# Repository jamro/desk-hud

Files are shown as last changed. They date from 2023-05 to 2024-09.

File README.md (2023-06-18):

# Desk-HUD

Desk-HUD is a compact side monitor designed to enhance productivity and convenience in your workspace. It features an 11.9-inch touch screen connected to a Raspberry Pi hardware platform, providing quick access to essential features like a todo list, calendar, weather updates, clock, and smart device control for items such as window covers and air conditioning. With Desk-HUD, managing tasks, staying organized, and controlling your environment becomes effortless, all while keeping everything you need within reach on your desk.

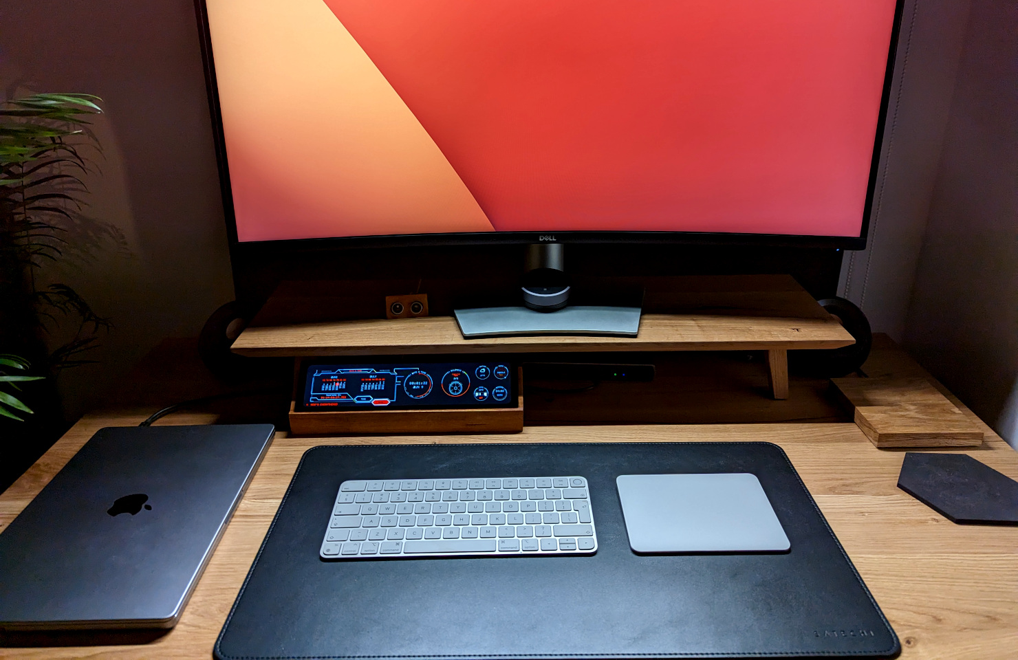
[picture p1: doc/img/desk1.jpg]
Desk view 1


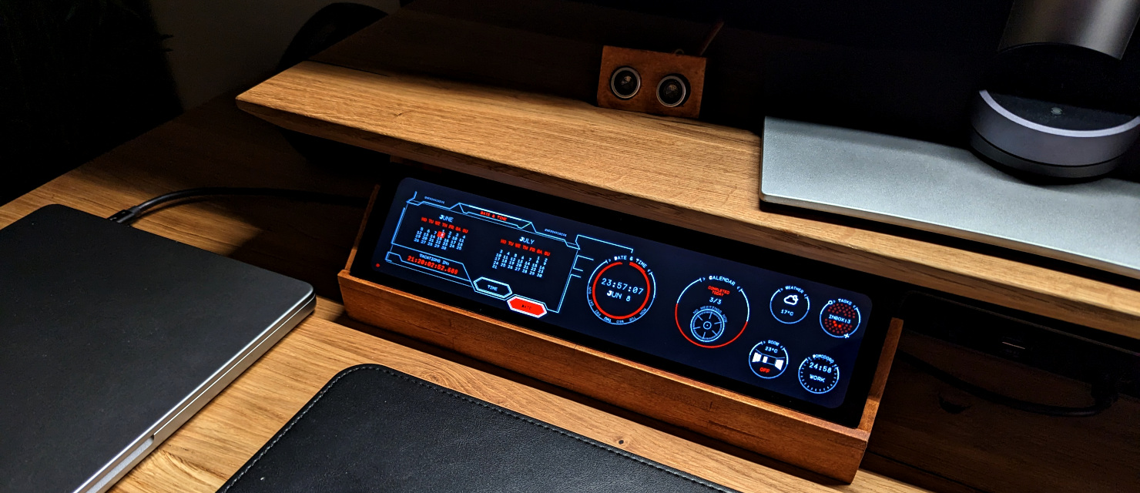
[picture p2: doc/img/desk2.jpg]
Desk view 2


# Key Features

## Date & Time Widget

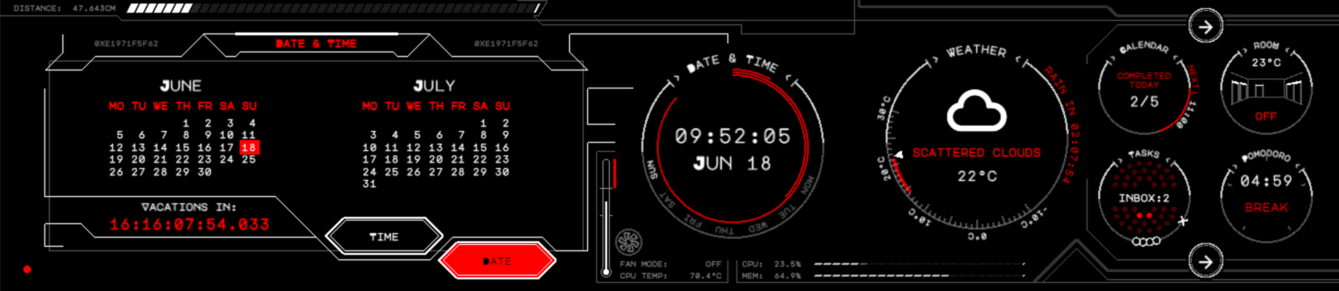
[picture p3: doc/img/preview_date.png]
Date preview


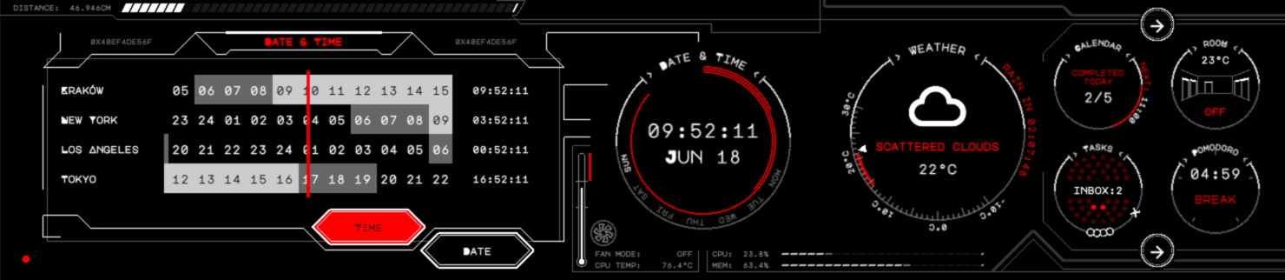
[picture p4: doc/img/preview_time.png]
Time preview


- Clock and calendar
- Special event countdown
- Timezones time conversion

## Weather Widget

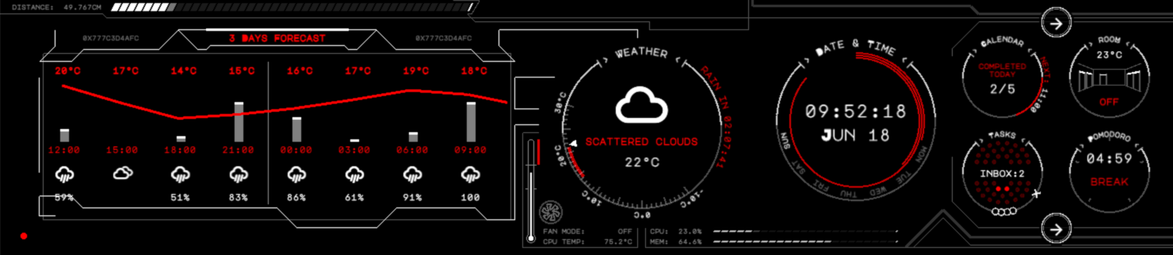
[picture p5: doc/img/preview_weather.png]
Weather preview


- Current weather
- Temperature range for today
- Rain countdown
- Forecast for upcoming days

## Room Widget

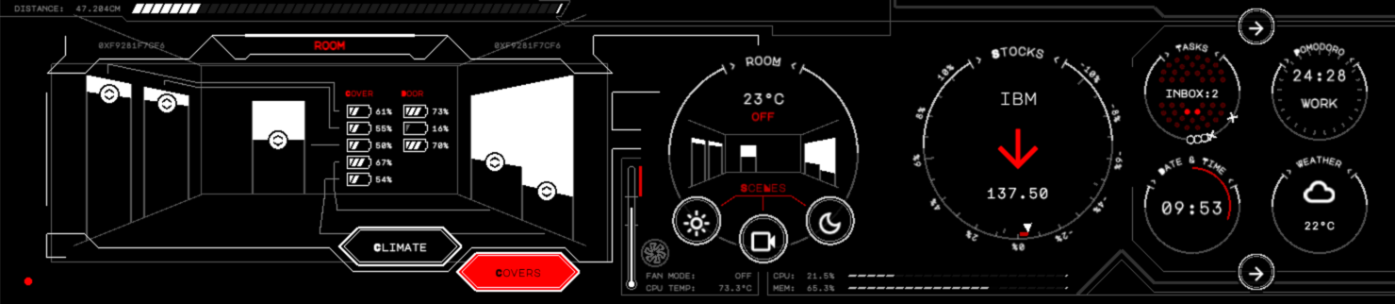
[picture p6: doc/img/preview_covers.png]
Covers preview


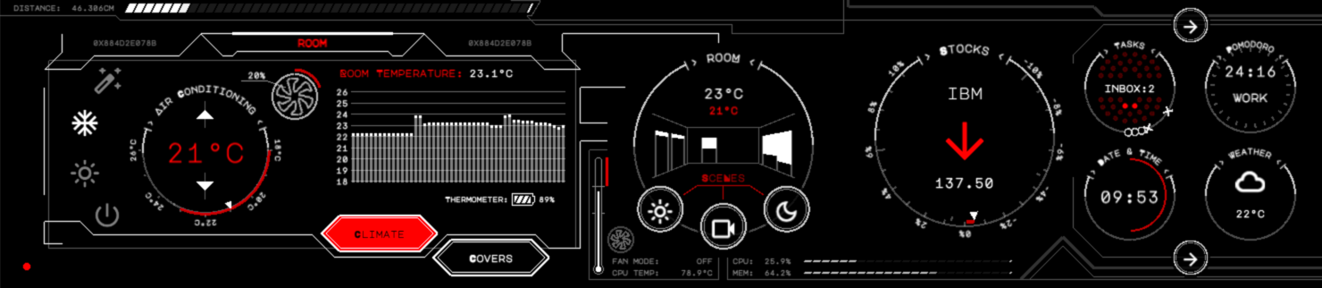
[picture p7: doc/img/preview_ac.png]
Airconditioning preview


- Manual control of window covers
- Window covers scenes: Day, Night, Vide-call (reduced back-light)
- Monitor batteries of smart devices
- Open window alerts
- Air Conditioning control
- Current room temperature
- Room temperature history

## Calendar Widget

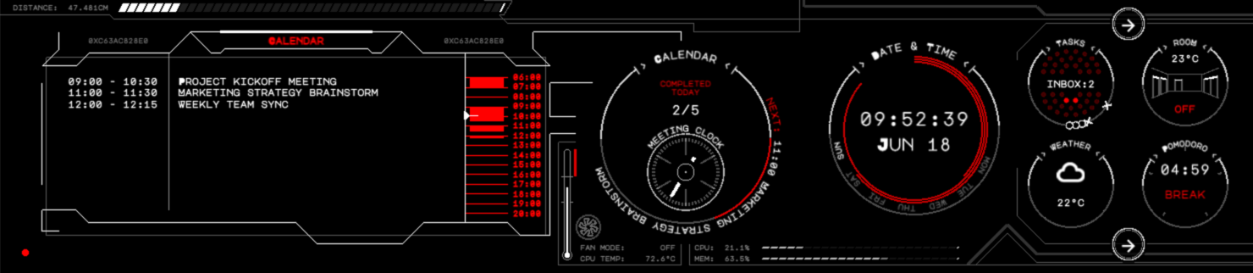
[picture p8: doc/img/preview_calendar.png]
Calendar preview


- Today's meetings
- Busy/available timeline
- Next meeting info
- Ongoing meeting clock

## Todo Widget

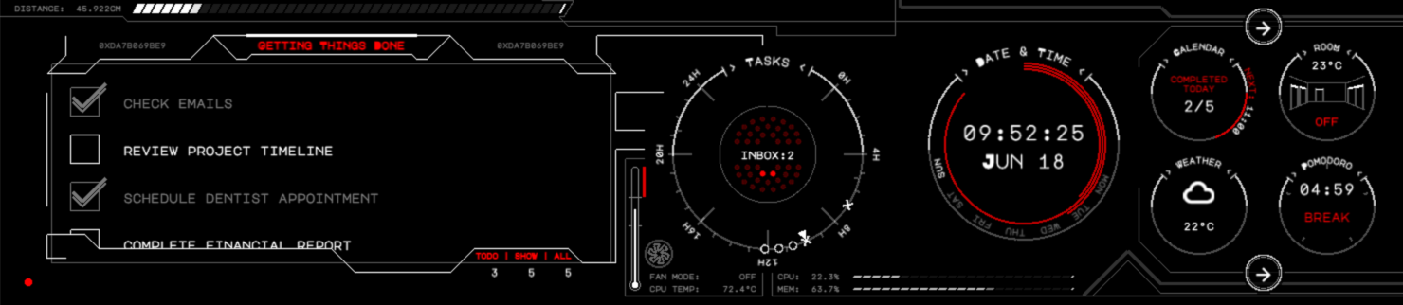
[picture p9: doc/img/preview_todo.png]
Todo preview


- Compatible with [Getting Things Done](https://gettingthingsdone.com/) approach
- List tasks for today
- Complete tasks
- Visualize task completion timeline
- Task inbox status

## Pomodoro Widget

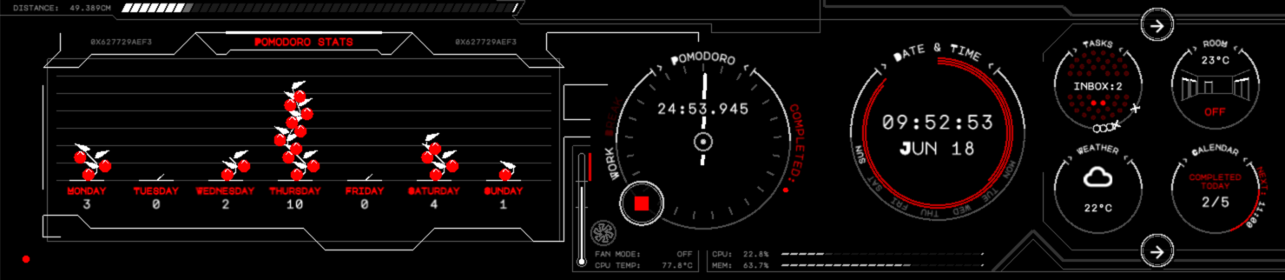
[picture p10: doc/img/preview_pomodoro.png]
Pomodoro preview


- Timer supporting [Pomodoro technique](https://en.wikipedia.org/wiki/Pomodoro_Technique)
- Last week history 

## Stocks Widget

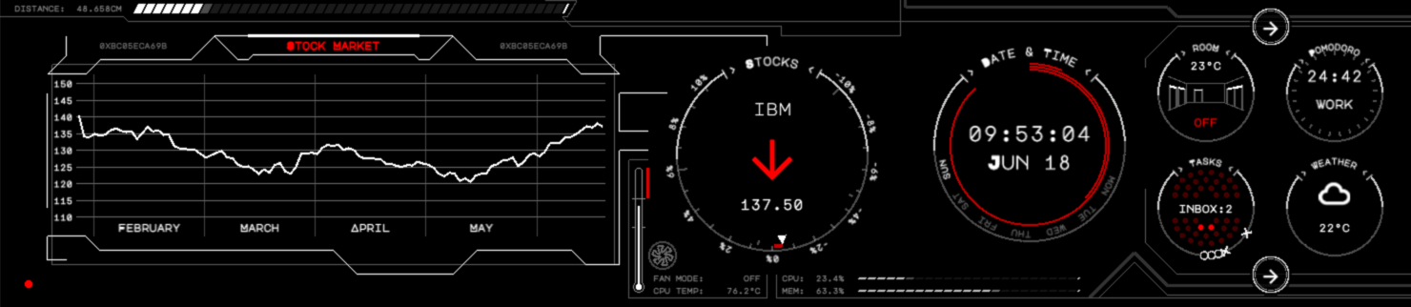
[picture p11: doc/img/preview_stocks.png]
Stocks preview


- Current stock price
- Daily change of the price
- Last months stock history

## Distance sensor

Distance preview

- Darken the screen when no one is around
- Activate Desk HUD automatically by approaching the desk
- Power the screen off when inactive

## System Monitoring

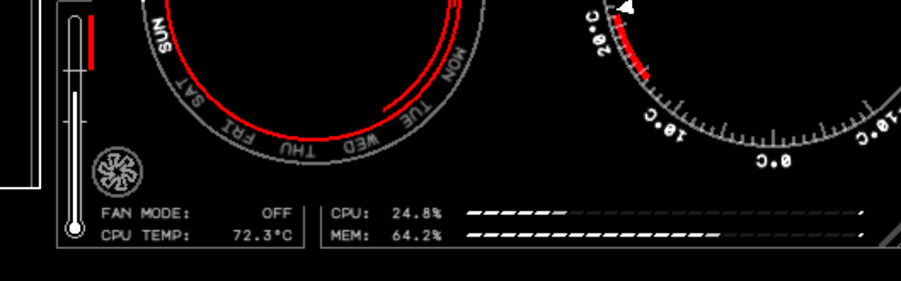
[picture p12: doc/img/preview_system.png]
System preview


- Monitor Desk HUD CPU and memory usage
- Monitor CPU temperature
- Control CPU fan (on/off/auto)

# Demo

You can experience a demo of Desk-HUD by visiting the following URL: [https://desk-hud.jmrlab.com](https://desk-hud.jmrlab.com). Please note that the demo uses simulated data to showcase the features, giving you a feel for Desk-HUD's functionality and is not connected to real systems. 

Additionally, there is a [video](https://www.youtube.com/watch?v=2UuWsG3Lnaw) showcasing the assembled project, complete with the wooden case and touch screen monitor.

# Installation Guide

- [Hardware setup](doc/install_hardware.md)
- [Software installation](doc/install_software.md)
- [Configuration](doc/configuration.md)
- [Wooden case assembly instructions](doc/install_case.md)

# Customization

Desk-HUD is specifically tailored to meet my unique requirements and is not intended as a one-size-fits-all solution. However, the project's source code is open for anyone to fork and customize according to their individual needs and preferences.

Some resources to get started:

- [System Design](doc/system_desgn.md)
- [Setup of Development Environment](doc/dev_setup.md)
- [Development Guide: Create a widget](doc/dev_create_widget.md)

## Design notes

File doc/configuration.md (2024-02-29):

# Configuration

## Location

By default, the configuration file, `desk-hud-config.json` is read from the root directory of the project. However, if you wish to use an alternative location for the config file, you can set the environment variable `DHUD_CONFIG` to the desired file path. This allows for flexibility in specifying the location of the config file to suit your needs. 

To assist you in creating the config file, a template named `desk-hud-config.default.json` is provided within the project. You can refer to this template as a starting point to define your own configurations and customize Desk-HUD according to your preferences.

## Config parameters

The configuration for Desk-HUD is stored in a JSON file.

- **core**: This section contains core settings for Desk-HUD.
  - `port` (number): The port number on which Desk-HUD's server runs.
  - `distance` (object): The distance settings for the distance sensor, specifying the threshold values for waking up and going to sleep modes.
    - `wakeUp` (number): The distance threshold (in centimeters) at which Desk-HUD wakes up from sleep mode.
    - `goSleep` (number): The distance threshold (in centimeters) at which Desk-HUD goes into sleep mode.
  - `powerOffTime` (number): The duration in milliseconds after which Desk-HUD's monitor powers off.

- **dateTime**: This section handles date and time widget configuration
  - `countdown` (object): Specifies a countdown timer with a name and a target date.
    - `name` (string): The name of the countdown timer.
    - `date` (string): The target date for the countdown timer in ISO 8601 format.
  - `timezones` (array): Defines an array of time zones with their IDs and corresponding names.
    - Each timezone object has the following properties:
      - `id` (string): The ID of the time zone.
      - `name` (string): The corresponding name of the time zone.

- **weather**: This section includes settings for weather information.
  - `apiKey` (string): The API key required to access weather data.
  - `lat` (number): The latitude coordinate of the location for weather information.
  - `lon` (number): The longitude coordinate of the location for weather information.

- **hass**: This section pertains to Home Assistant integration.
  - `url` (string): The URL of the Home Assistant instance.
  - `token` (string): The authentication token for Home Assistant.
  - `entities` (object): Defines a mapping of entity names used in Desk-HUD
    - `temp` (string): The entity ID for the temperature sensor.
    - `tempBattery` (string): The entity ID for the temperature sensor battery status.
    - `ac` (string): The entity ID for the air conditioning system.
    - `door1`, `door2`, `door3` (string): The entity IDs for binary door sensors.
    - `cover1`, `cover2`, `cover3`, `cover4`, `cover5` (string): The entity IDs for window cover devices.
    - `door1Battery`, `door2Battery`, `door3Battery` (string): The entity IDs for the battery status of the door sensors.
    - `cover1Battery`, `cover2Battery`, `cover3Battery`, `cover4Battery`, `cover5Battery` (string): The entity IDs for the battery status of the window cover devices.

- **google**: This section pertains to Google integration.
  - `clientId` (string): The client ID for Google integration.
  - `clientSecret` (string): The client secret for Google integration.
  - `clientToken` (string): The client token for Google integration.
  - `tasks` (object): Contains settings related to Google Tasks integration.
    - `inboxId` (string): The ID of the Google Tasks inbox (see Getting Things Done technique).
    - `actionsId` (string): The ID of the Google Tasks actions list (see Getting Things Done technique).
  - `calendars` (array): An array of Google Calendars IDs.

- **stockdata** - allows you to configure the [StockData](http://www.stockdata.org) service integration for Desk-HUD. StockData provides financial market data and analytics.
  - `apiKey` (string): The API key for accessing the StockData service.
  - `symbol` (string): The stock symbol or ticker for which you want to fetch data. 

## Integrations

### Open Weather Maps

To obtain the weather.apiKey for Desk-HUD, you will need to sign up on the OpenWeatherMap website and obtain an API key. Here are the steps to get the API key:

1. Visit the [OpenWeatherMap website](https://openweathermap.org/).
2. Sign up for a free account or log in to your existing account.
3. Once logged in, navigate to the `My API Keys` section.
4. Generate a new API key by clicking on the "Generate" button.
5. Once the API key is generated, copy it to your clipboard.
6. Paste the API key into the `weather.apiKey` parameter in the Desk-HUD configuration file.

### Home Assistant

1. Log in to your Home Assistant instance.
2. Navigate to your user profile or user settings.
3. Locate the "Long-Lived Access Tokens" section.
4. Generate a new access token by clicking on the "Create Token" or similar button.
5. Provide a name for the token to identify its purpose (e.g., "Desk-HUD Integration").
6. Once the token is generated, copy it to your clipboard or save it in a secure location.
7. Paste the Home Assistant token into the corresponding `hass.token` parameter in the Desk-HUD configuration file.

### Google

To set up Google access keys for integration with Desk-HUD, follow these steps:

- In the Google Cloud console, go to Menu `APIs & Services` > `Credentials`.
- Click `Create Credentials` > `OAuth client ID`.
- Click `Application type` > `Desktop app`.
- In the `Name` field, type a name for the credential. This name is only shown in the Google Cloud console.
- Click `Create`. The OAuth client created screen appears, showing your new Client ID and Client secret.
- Click `OK`. The newly created credential appears under OAuth 2.0 Client IDs.
- Save the downloaded JSON file as `credentials.json`
- Open `OAuth consent screen` and yourself to `Test users`
- Once you have `credentials.json`, run the `node ./google_auth.js` script. Follow the instructions provided to complete the authentication process.

Detailed process of obtaining `credentials.json` is described here [here](https://developers.google.com/tasks/quickstart/nodejs)

** Refreshing Access Token **
If your access token has expired, you need to remove `clientSecret` and `clientToken` from `deck-hud-config.json` and rerun `node ./google_auth.js` script.

### StockData

- Visit the StockData website: Go to the StockData website at http://www.stockdata.org.
- Click "Sign In"
- Crete an account
- Get API token and copy it to config file

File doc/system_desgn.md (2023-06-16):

# System Design

Desk-HUD utilizes a client-server architecture where both the client and server components run on the same machine, leveraging the Raspberry Pi hardware platform. The server is implemented in JavaScript using Node.js with Express.js and Socket.IO, and it runs locally at localhost:3000. The client is implemented in JavaScript and utilizes Pixi.js for rendering graphics.

On the client side, multiple widgets runs, each corresponding to a specific backend service. These widgets communicate with their respective backend services to retrieve and display relevant data. This modular design allows for flexibility and scalability in adding or modifying widgets based on individual preferences and requirements.

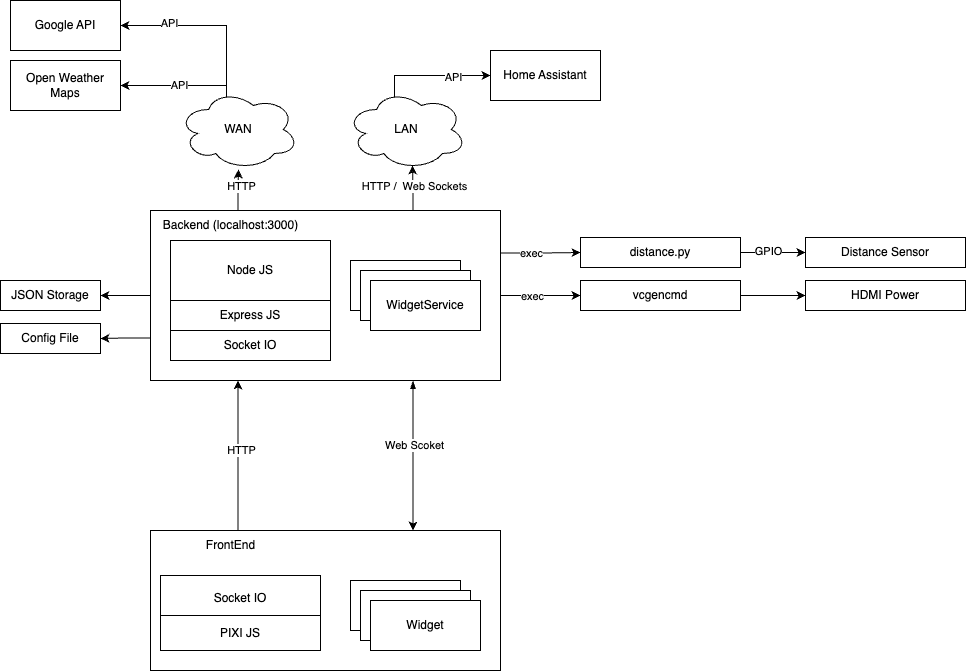
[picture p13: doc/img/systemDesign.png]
System Design Diagram


## Communication

Communication between the client and server is established through web sockets, allowing real-time data exchange. Additionally, an HTTP connection is used to serve static content to the client. This architecture enables seamless and efficient communication between the two components.

The server component of Desk-HUD encompasses multiple services, each responsible for the logic of a specific widget. These services handle data retrieval, processing, and communication with external APIs such as Google API, Open Weather Maps, or Home Assistant. The server also controls peripherals connected to the Raspberry Pi, including a distance sensor and the power of the HDMI monitor.

### Incoming messages

There are several web socket events emitted by the server:

- `config` - configuration details sent after client connected
- `widget` - update of widget data. The message is specific to each eidget
- `distance` - updates from distance sensor
- `system` - updates from system monitor
- `log` - stream of server side logs to show them in browser's dev tool console

### Outgoing messages

There is one web socket event emitted by the client:

- `service` - command for the service (e.g. turn the air conditioning off)

## Persistance

To store essential data, the server employs simple JSON files on the local disk, utilizing the `node-persist` library. This approach ensures persistence and accessibility of necessary information for the widgets and services.

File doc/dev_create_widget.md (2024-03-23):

# Development Guide - Create a widget

This tutorial shows how to create and add a new widget to Desk HUD. During this walkthrough, 
we are going to create "Memory" widget which monitors memory usage on Raspberry PI device

## Initialize an empty widget

- Create new folder for the widget at `src/widgets/memory`
- Create widget class `src/widgets/memory/MemoryWidget.js`:
```js
import Widget from '../../frontend/Widget.js'

export default class MemoryWidget extends Widget {
  constructor() {
    super('memory', "Memory")

    // set header of main widget window
    this.main.title = "memory stats"
  }
}
```
- Add new widget to `src/widgets/widgets.js`:
```js
import MemoryWidget from './memory/MemoryWidget'
...
const widgets = [
  ...,
  MemoryWidget
]
```

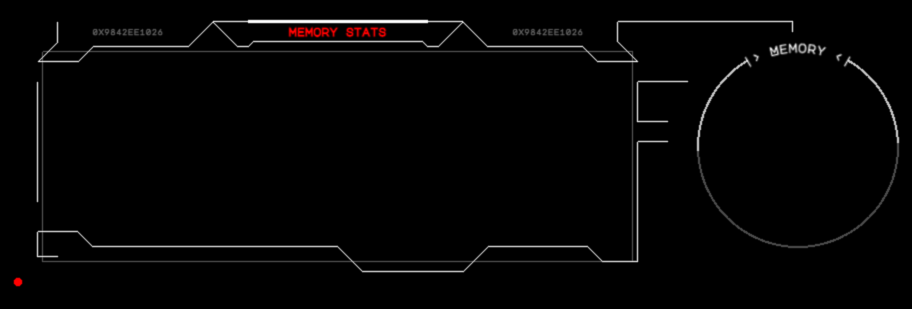
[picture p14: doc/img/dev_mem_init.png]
Empty widget


## Integrate backend service

- Create widget class `src/widgets/memory/MemoryService.js`:
```js
const Service = require("../../backend/services/Service");
const os = require('os');

class MemoryService extends Service {

  constructor(config, io) {
    super(config, io, 'memory')
    this._loop = null
  }

  async start() {
    if(this._loop) {
      clearInterval(this._loop)
    }
    // send update over web socket to the client every 1000ms
    this._loop = setInterval(() => this.update(), 1000)
    this.update()
  }

  async welcomeClient(socket) {
    // send memory usage to the client once it is connected
    this.emit(this.getMemoryUsage(), socket)
  }

  update() {
    // send memory usage updates regularly 
    this.emit(this.getMemoryUsage())
  }

  getMemoryUsage() {
    return {free: os.freemem(), total: os.totalmem()}
  }
}

module.exports = MemoryService
```

- Add new service to `src/widgets/services.js`: 
```js
const MemoryService = require("./memory/MemoryService")
...

const services = [
  ...,
  MemoryService
]
module.exports = services
```

- Extend `MemoryWidget` to display data sent by the service:
```js
import Widget from '../../frontend/Widget.js'
import TextField from '../../frontend/components/TextField.js'

export default class MemoryWidget extends Widget {
  constructor() {
    super('memory', "Memory")

    // set header of main widget window
    this.main.title = "memory stats"

    // store memory usage sent from MemoryService
    this.initState({ usage: 0 })

    // text field to shot memory usage
    this._usageLabel = new TextField('', {
      fontFamily: 'MajorMonoDisplay-Regular',
      fontSize: 15,
      fill: '#ffffff',
      stroke: "#ffffff",
      strokeThickness: 0.5,
      align: 'center',
    })
    this.addChild(this._usageLabel)
  }

  msg2state(msg) {
    // update widget's state and store memory usage there
    return {
      usage: 1 - msg.free / msg.total
    }
  }

  render(renderer) {
    // play nice appear / disappear animations
    this._usageLabel.progress = this.progress

    // display memory usage
    this._usageLabel.text = (100*this.state.usage).toFixed(2) + '%'

    // render the component
    super.render(renderer)
  }
}
```

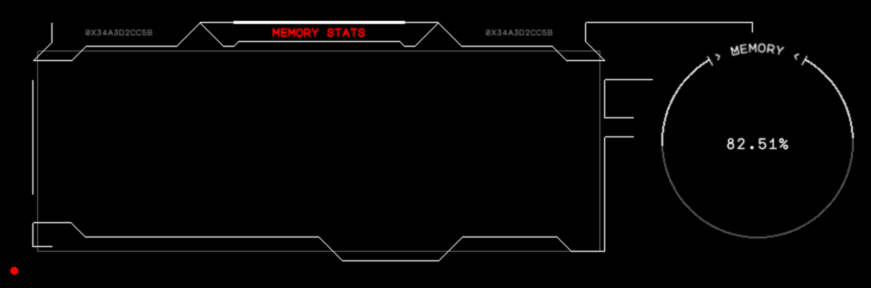
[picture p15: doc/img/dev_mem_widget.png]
Service sending data to the widget


## Store history of memory usage

- Extend `MemoryService` to store the history of memory usage
```js
class MemoryService extends Service {

  constructor(config, io) {
    // ...
    this._history = []
  }

  // ...

  update() {
    this._history.push(os.freemem())
    // limit the history to last minute (60 data points)
    while(this._history.length > 60) {
      this._history.shift()
    }

    // send memory usage updates regularly 
    this.emit(this.getMemoryUsage())
  }

  getMemoryUsage() {
    return {
      free: os.freemem(), 
      total: os.totalmem(),
      history: this._history
    }
  }
}

module.exports = MemoryService
```

- Extend `MemoryWidget` to display memory usage history
```js
import BarChart from '../../frontend/components/BarChart.js'

export default class MemoryWidget extends Widget {
  constructor() {
    // ...

    // create usage chart at main screen
    this._usageChart = new BarChart({
      height: 150,
      width: 530
    })
    this._usageChart.x = -260
    this._usageChart.y = -80
    this.main.getPage(0).addChild(this._usageChart)
  }

  msg2state(msg) {
    // update widget's state and store memory usage there
    return {
      usage: 1 - msg.free / msg.total,
      history: msg.history.map(free => 100 * (1 - free / msg.total))
    }
  }

  render(renderer) {
    // ...
    
    // update usage chart
    this._usageChart.progress = this.progress
    this._usageChart.data = this.state.history

    // render the component
    super.render(renderer)
  }
}
```

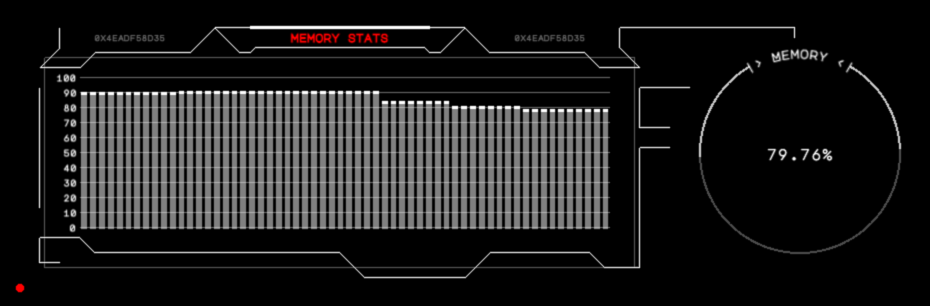
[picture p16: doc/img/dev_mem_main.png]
Usage history integrated


## Error messages

```js
class MemoryService extends Service {

  update() {
    // turn widget into error state and show message
    this.emit({error: "My error message"})
    
    // clear error message
    this.emit({error: null})
  }
}

```

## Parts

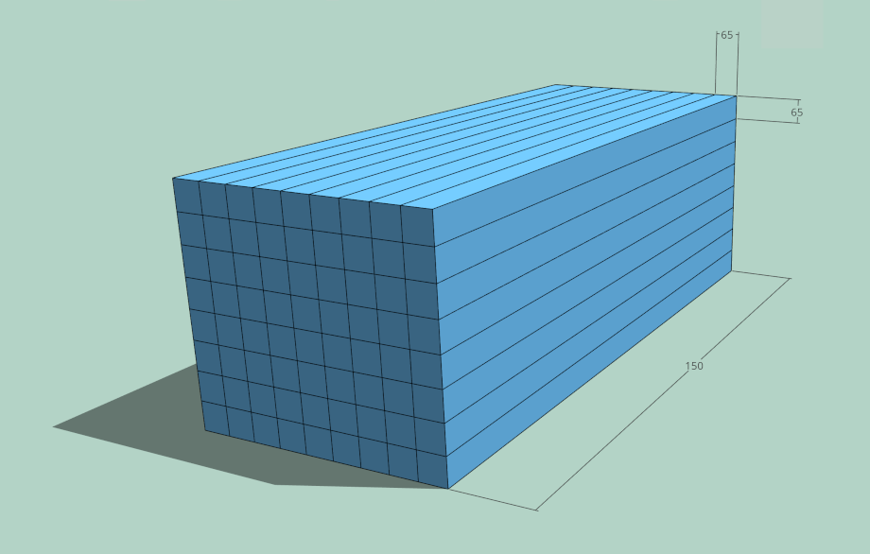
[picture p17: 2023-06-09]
doc/img/components1.png

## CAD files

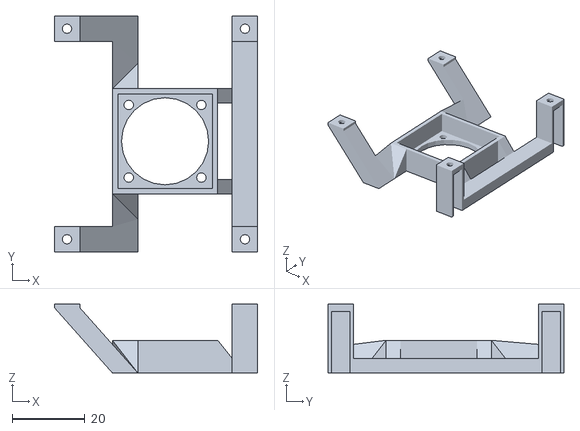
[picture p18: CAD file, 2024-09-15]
doc/stl/desk-hud-fan-mount.stl
56.0 x 65.0 x 19.0

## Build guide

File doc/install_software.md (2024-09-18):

# Install Guide - Software

## Setup project on local machine

- Clone reporistory `git clone https://github.com/jamro/desk-hud.git`
- Enter project folter `cd desk-hud`
- Install dependencies `npm i`
- Rename `desk-hud-config.default.json` to `desk-hud-config.json` and fill missing data. See detailed instructions in [Configuration section](./configuration.md)

## Configuration of Raspberry PI

- Start Raspberry PI and open Terminal 
- change hostname to `deskhud.local`
- Enable ssh `sudo raspi-config`
- Open terminal on your local machine
  - generate public and private keys `ssh-keygen`
  - copy public key to remote host `ssh-copy-id -i ~/.ssh/id_rsa.pub pi@deskhud.local`
  - add key to ssh: `ssh-add`
  - connect to Raspberry PI: `ssh pi@deskhud.local`
- Install Node.js 
```bash
sudo su
curl -fsSL https://deb.nodesource.com/setup_18.x | bash -
sudo apt-get install -y nodejs
```
- Install PM2 `sudo npm install pm2@latest -g`
- Install PM@ log rotate `pm2 install pm2-logrotate`
- Create app folder
```bash
sudo mkdir /var/www
sudo chown pi /var/www
```
- setup env var with path to config file and add it to: `sudo nano /etc/environment`
```
DHUD_CONFIG=/home/pi/desk-hud-config.json 
```
- Expand filesystem `sudo raspi-config` > `Advanced Options` > `Expand Filesystem`
- Disable screen saver `xset s off` (on a Terminal running on Raspberry PI Desktop)
- On your local machine
  - copy config to Raspberry PI: `scp desk-hud-config.json pi@deskhud.local:/home/pi/desk-hud-config.json`
  - provision remote host `npm run provision-remote`
  - deploy `npm run deploy`
- on Raspberry Pi Desktop, open web browser, go to http://localhost:3000 and go full screen

## Enable auto start after boot
- connect to Raspberry PI: `ssh pi@deskhud.local`
- make sure PM2 starts automatically after boot `pm2 startup`
- edit autostart: `nano ~/.config/wayfire.ini` and add following lines
```
[autostart]
command = chromium-browser --kiosk http://localhost:3000/
```
- Reload of the page may be necessary sine Desk-HUD server may not be immediately available 

In order to exit Chromium kiosk mode, press Ctrl+F4

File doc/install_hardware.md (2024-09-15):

# Install Guide - Hardware

## Shopping List

Necessary hardware:
- [Raspberry PI 5](https://www.raspberrypi.com/products/raspberry-pi-5/)
- [Waveshare 11.9inch HDMI touch screen](https://www.waveshare.com/11.9inch-hdmi-lcd.htm)
- [SparkFun Ultrasonic Distance Sensor - HC-SR04](https://www.sparkfun.com/products/17777)
- [Jumper Wires female-female](https://blog.sparkfuneducation.com/what-is-jumper-wire)
- [32GB SD Card with Raspberry Pi OS](https://projects.raspberrypi.org/en/projects/raspberry-pi-setting-up/2)
- [Angle USB-C Cable](https://eu.ugreen.com/collections/cables/products/ugreen-usb-c-to-usb-c-cable-60w-1?variant=40400840556627)
- [20W USB Charger](https://eu.ugreen.com/collections/chargers/products/power-supply-pd-3-0?variant=40296226586707)
- [Raspberry Pi 4 Fan and Heatsink](https://www.adafruit.com/product/4794)
- [3D printed fan mount](stl/desk-hud-fan-mount.stl) (Optional)

## Assembly hardware

Mount Raspberry PI to the [touch screen](https://www.waveshare.com/11.9inch-hdmi-lcd.htm) with included screws and distances. Connect HDMI and touch screen USB with included adapters. Install SD Card with Raspberry PI OS.

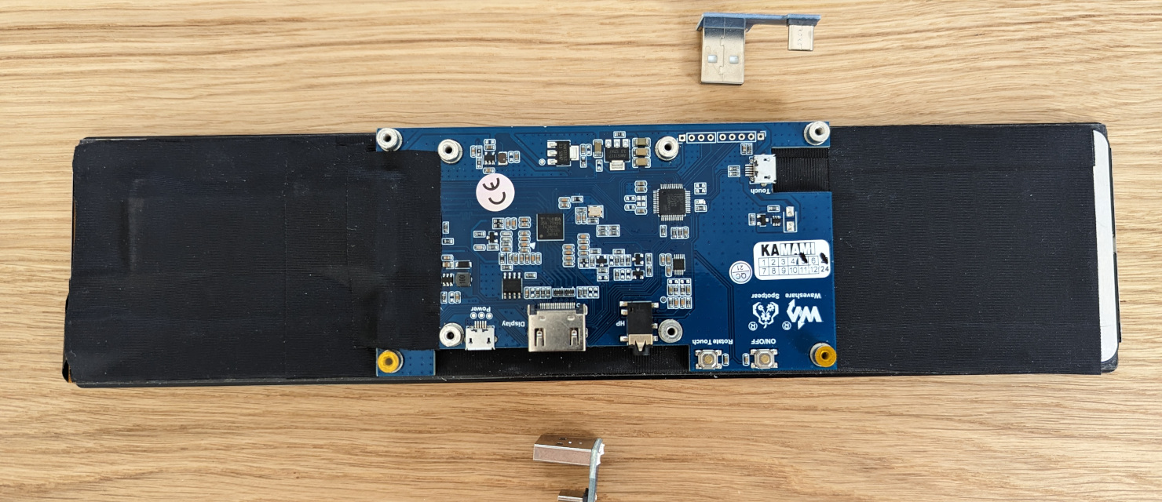
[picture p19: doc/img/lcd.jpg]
Touch screen back


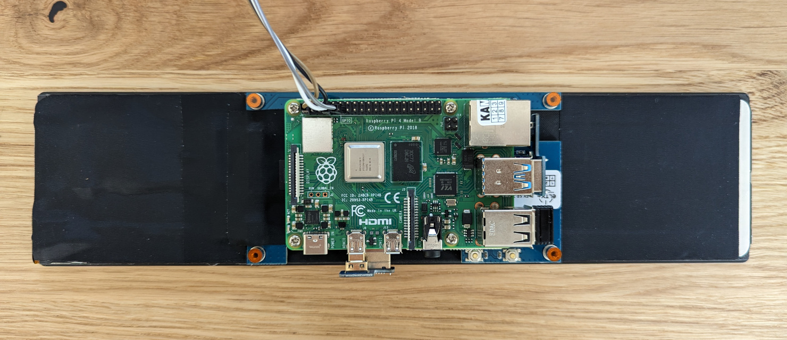
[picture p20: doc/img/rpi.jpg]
Raspberry PI + Touch screen


Wire [distance sensor](https://www.sparkfun.com/products/17777) to GPIO pins of Raspberry PI. Connect the GND at first, otherwise, it will affect the normal work of the module.  

Wire fan to ensure proper cooling of the device. Mount the fan to the case in the place where it can efficiently cool the CPU down. Install the heatsink on Raspberry PI CPU.

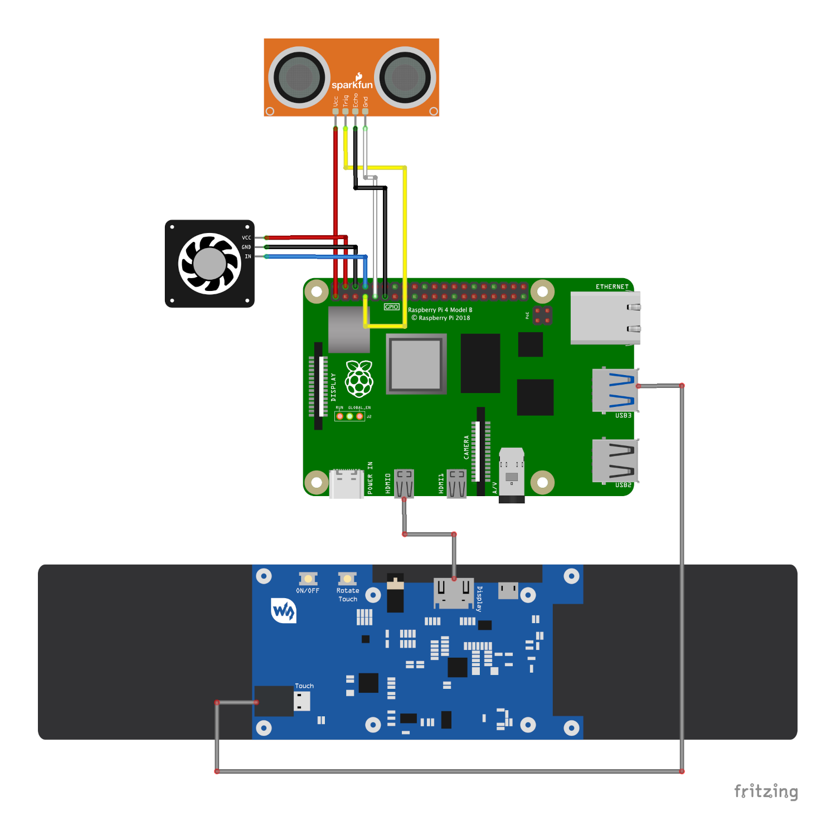
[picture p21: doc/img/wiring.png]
Wireing


3D print the [fan mount](stl/desk-hud-fan-mount.stl) and mount it to the case.

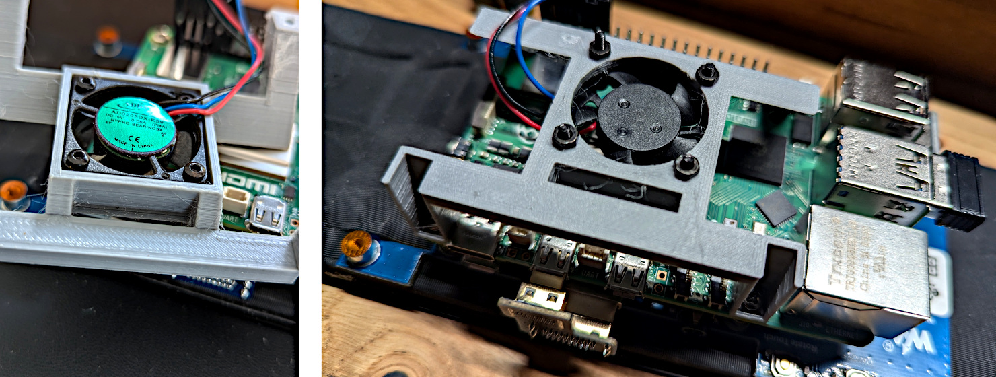
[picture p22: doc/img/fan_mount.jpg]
Fan mount


Power up Raspberry PI by connecting to USB charger. Make sure that touch screen is working correctly. It may have wrong orientation. Fix it using "Rotate Touch" button on the back of the screen 

## Troubleshooting

### Screen is Rotated
1. Open `Menu` > `Preferences` on Raspberry Pi
2. Select `Screen Configuration`.
3. In the new window, right-click the display.
4. Select `Orientation` and choose one of the four options (most probably **Left**).
5. Click the green check to confirm and apply the new orientation.

### Touch Screen is Rotated
- Use the hardware button on the back of the screen to change the orientation of the touchscreen.

### Screen is Black
1. **Ensure Power Supply:** Make sure your Raspberry PI is powered with a 5A power supply (25W or more).
2. **Toggle Power:** Try to turn the screen on/off using the physical button on the screen.
3. **Test with Secondary Screen:** Connect the Raspberry PI to another screen through HDMI output to verify if the Raspberry PI is working correctly.
4. **Direct Power to Screen:** Connect the power supply directly to the screen and HDMI cable from the screen to the Raspberry PI to check if the screen functions.
5. **USB Cable Power:** Replace the power supply by connecting a USB cable directly to the Raspberry PI to see if it provides enough power to the screen.
6. **Check Cables:** Replace the HDMI and USB cables with the connectors included in the screen kit to ensure they are functioning correctly.

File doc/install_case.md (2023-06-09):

# Install Guide - Wooden Case

The wooden case for Desk HUD is built from square sticks glued together. You will need the following materials and follow these step-by-step instructions:

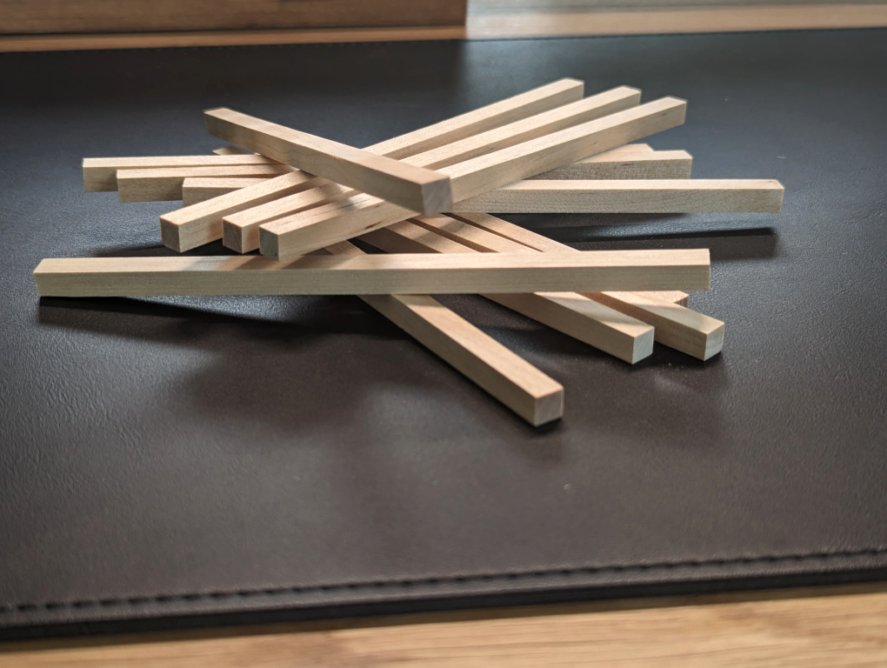
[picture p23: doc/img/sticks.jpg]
Wooden Sticks


## Materials:

- 72 Wooden square sticks: 150mm x 6.5mm x 6.5mm
- Wood glue
- Sandpaper
- Oak-colored paint or wood stain

## Instructions:

Begin by preparing the wooden sticks. Keep 38 sticks at the length of 150mm, cut 24 sticks to 75mm, 2 sticks to 65mm, and 62 sticks to 50mm. Ensure all the cuts are clean and accurate.

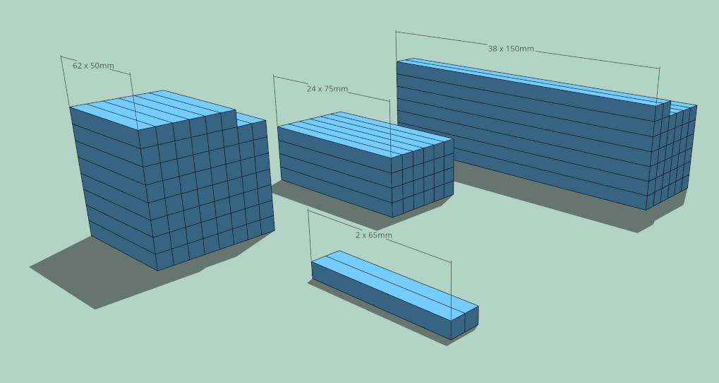
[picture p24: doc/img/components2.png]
Components


Start building the first layer of the case. Apply a thin layer of wood glue on the sides of the sticks and press them together firmly. Ensure the sticks are aligned properly. Allow the glue to dry according to the manufacturer's instructions before proceeding to another layer

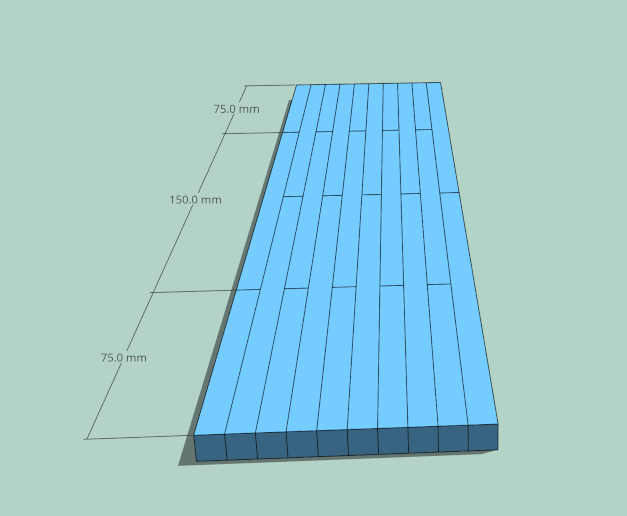
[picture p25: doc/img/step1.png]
Step 1


Repeat the previous step to assemble the subsequent layers of the case, following the provided images as a guide. Take care to align the sticks accurately and maintain the desired shape and dimensions of the case.

Step 2

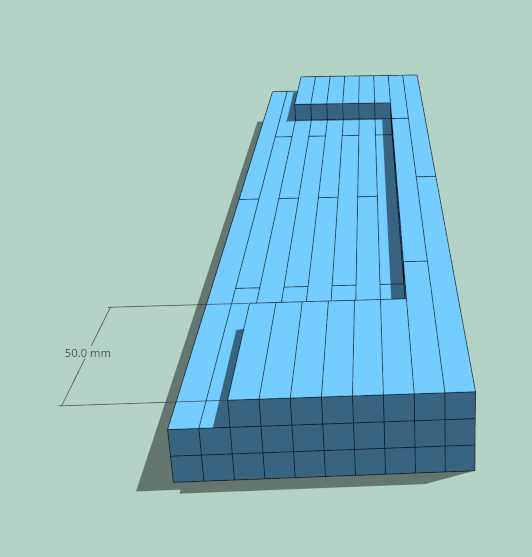
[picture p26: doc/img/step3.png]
Step 3


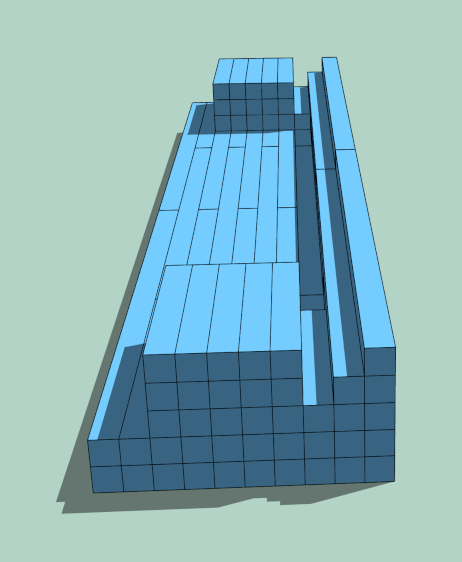
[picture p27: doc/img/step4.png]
Step 4


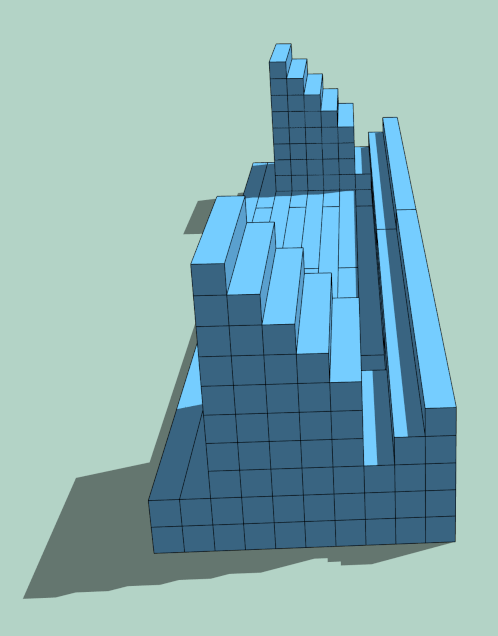
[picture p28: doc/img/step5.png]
Step 5


Use sandpaper to remove corners of the stairs-like surface and turn it into a smooth edge.

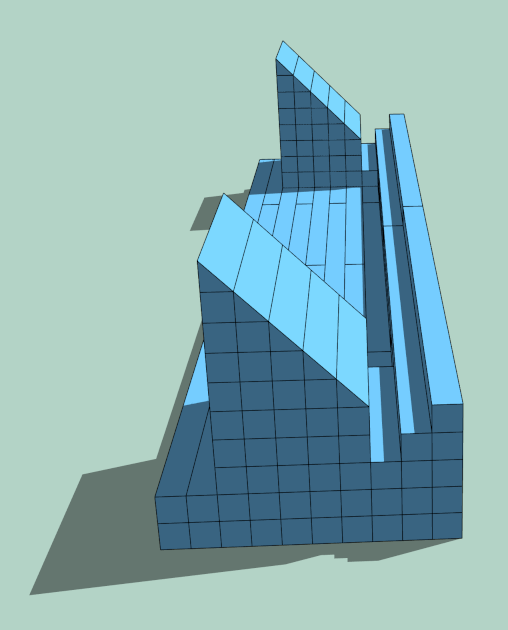
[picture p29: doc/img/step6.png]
Step 6


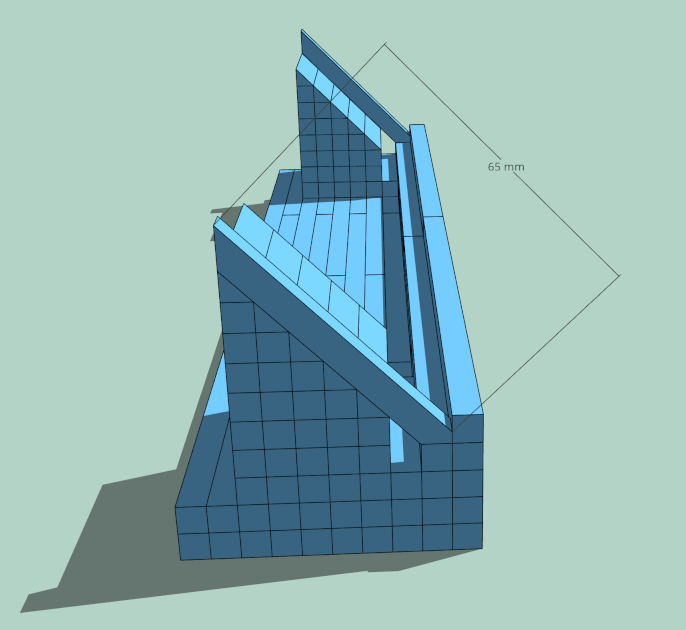
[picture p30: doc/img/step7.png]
Step 7


Step 7

After the glue has dried, use sandpaper to smooth out any rough edges or imperfections on the case. Ensure all surfaces are even and smooth to create a cohesive and solid body.

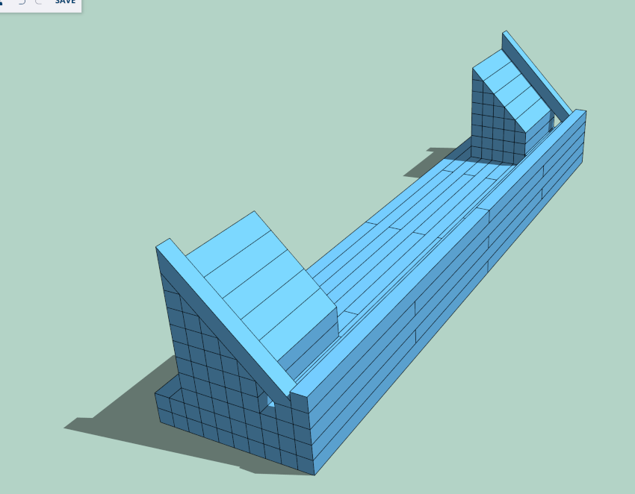
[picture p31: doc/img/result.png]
Result


Once the case is smooth, you can apply an oak-colored paint or wood stain of your choice. Follow the instructions on the paint/stain product for the best results. Apply multiple coats if necessary, allowing proper drying time between each coat.

After the paint or stain has dried completely, your wooden case for Desk-HUD is ready! You can now place the hardware components inside the case and enjoy its design.

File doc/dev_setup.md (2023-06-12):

# Setup of Development Environment

## Setup project on local machine

- Clone reporistory `git clone https://github.com/jamro/desk-hud.git`
- Enter project folter `cd desk-hud`
- Install dependencies `init i`
- Rename `desk-hud-config.default.json` to `desk-hud-config.json` and fill missing data. See detailed instructions in [Configuration section](./configuration.md)

## Run development mode

- start backend services: `npm run deploy-local`
- run build of frontend in watch mode: `npm run watch`
- open [http://localhost:3000](http://localhost:3000)

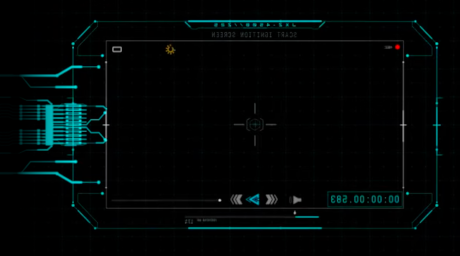
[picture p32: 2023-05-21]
build/assets/panel.png

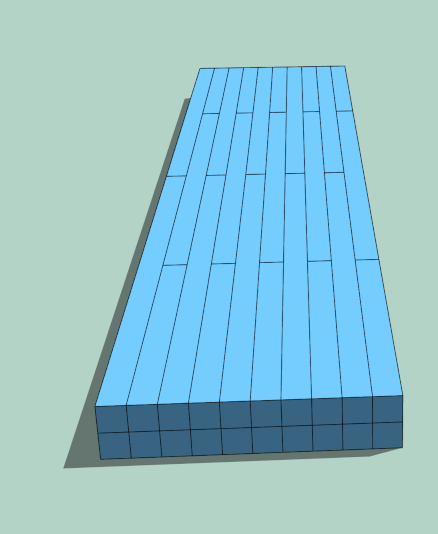
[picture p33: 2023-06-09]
doc/img/step2.png

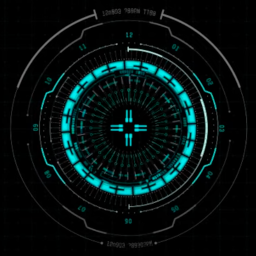
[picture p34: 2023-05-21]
build/assets/circle.png

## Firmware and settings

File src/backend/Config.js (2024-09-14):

const path = require('path')
const fs = require('fs').promises
require('dotenv').config()

class Config {

  constructor(logger) {
    this._logger = logger
    this._json = {}
  }

  get coreLogger() {
    return this._logger
  }

  get isDevMode() {
    return process.env.DHUD_ENV === 'development'
  }

  _getConfigPath() {
    let configPath = process.env.DHUD_CONFIG
    if(!configPath) {
      configPath = path.resolve(__dirname, '..', '..', 'desk-hud-config.json')
    }
    configPath = configPath.trim();
    return configPath
  }

  async load() {
    let configPath = this._getConfigPath()
    this._logger.log(`Config path: ${configPath}`)
    try {
      const rawConfig = await fs.readFile(configPath, "utf-8");
      this._json = JSON.parse(rawConfig)
      this._logger.log('Configuration loaded successfully')
    } catch(err) {
      this._logger.log(`--------------------------------------------------------------------`)
      this._logger.log(`Unable to open configuration file`)
      this._logger.log(`- Make sure that desk-hud-config.json exists in projet root location`)
      this._logger.log(`  or DHUD_CONFIG env var is defined and points to config location`)
      this._logger.log(`- Make sure that config file is a valid JSON`)
      this._logger.log(`- Follow README.md to create a new config file`)
      this._logger.log(`--------------------------------------------------------------------`)
      throw err
    }
  }

  async save() {
    let configPath = this._getConfigPath()
    this._logger.log(`Config path: ${configPath}`)
    await fs.writeFile(configPath, JSON.stringify(this._json, null, 2))
    this._logger.log('Configuration saved successfully')
  }

  getProp(propPath) {
    const segments = propPath.split('.')

    let pointer = this._json
    while(segments.length > 0) {
      if(!pointer[segments[0]]) {
        throw new Error(`Config prop not fount at ${propPath}`)
      }
      pointer = pointer[segments.shift()]
    }

    return pointer
  }

  setProp(propPath, value) {
    const segments = propPath.split('.')

    let pointer = this._json
    while(segments.length > 1) {
      if(!pointer[segments[0]]) {
        pointer[segments[0]] = {}
      }
      pointer = pointer[segments.shift()]
    }
    pointer[segments[0]] = value


    return pointer
  }
}

module.exports = Config

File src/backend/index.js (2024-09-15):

require('dotenv').config()
const express = require('express')
const path = require('path')
const livereload = require("livereload");
const connectLiveReload = require("connect-livereload");
const http = require('http');
const { Server } = require("socket.io");
const Config = require('./Config.js');
const storage = require('node-persist');
const DistanceService = require('./services/DistanceService.js');
const SysMonitorService = require('./services/SysMonitorService.js');
const services = require('../widgets/services.js');
const SocketLogger = require('./SocketLogger.js');

(async () => {
  await storage.init()
  
  const app = express()
  const server = http.createServer(app);
  const io = new Server(server);

  const config = new Config(new SocketLogger(io))
  await config.load()

  const port = config.getProp('core.port')
  config.coreLogger.log("Desk HUD started")
  
  const liveReloadServer = livereload.createServer();
  liveReloadServer.server.once("connection", () => {
    setTimeout(() => {
      liveReloadServer.refresh("/");
    }, 100);
  });
  
  app.use(connectLiveReload());
  app.use(express.static(path.join(__dirname, 'www')))
  
  const serviceInstances = services.map((Def) => new Def(config, io, app))
  serviceInstances.push(new DistanceService(config, io))
  serviceInstances.push(new SysMonitorService(config, io))
 
  let watchDog
  try{
    const servicesStartingTime  = performance.now()
    watchDog = setInterval(() => {
      const startingDuration = Math.round((performance.now() - servicesStartingTime) / 1000)
      const notStarted = serviceInstances.filter(s => !s.started)
      notStarted.forEach(s => config.coreLogger.warn(`Service ${s.id} did not start after ${startingDuration} seconds`))

    }, 5000)

    await Promise.all(serviceInstances.map(s => new Promise(async (resolve, reject) => {
      try {
        await s.start()
        s.started = true
        resolve()
      } catch(err) {
        reject(err)
      }
    }
    )))
  } catch(err) {
    config.coreLogger.error('Unable to start services')
    config.coreLogger.error(err)
  } finally {
    if(watchDog) clearInterval(watchDog)
  }
  io.on('connection', async (socket) => {

    const logHistory = config.coreLogger.getHistory()
    config.coreLogger.emit(logHistory)

    config.coreLogger.log("Client connected")
    await socket.emit('config', {
      widgets: {
        dateTime: config.getProp('dateTime'),
        webcam: {
          name: config.getProp('webcam.name'),
          areas: config.getProp('webcam.areas'),
          stream: {
            buffer: config.getProp('webcam.stream.buffer')
          }
        }
      }
    })
    await Promise.all(serviceInstances.map(s => s.welcomeClient(socket)))
    socket.on('service', async ({serviceId, payload}) => {
      const service = serviceInstances.find(s => s.id === serviceId)
      if(service) {
        await service.onMessage(payload)
      }
    })
  });
  
  server.listen(port, () => {
    config.coreLogger.log(`app listening on port ${port}`)
  })
  
})()

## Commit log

2023-05-22 feat: add widget frames
2023-05-23 feat: add pomodoro timer
2023-05-26 fix: fix private key parsing
    [index.js]
2023-05-27 refactor: switch communication to web sockets
2023-05-28 refactor: migrate room widget to web sockets
2023-05-30 fix: handle services startup errors
    [index.js]
2023-05-30 refactor: integrate distance sensor
2023-05-31 fix: restart sensor monitor when not responding
    [Config.js, distance_mock.js, index.js]
2023-05-31 fix: mix manual and automatic control of sleep mode
    [distance_mock.js, index.js]
2023-05-31 fix: fix weather data parsing when no rain in forecast
    [distance_mock.js]
2023-05-31 fix: use room temperature from separate sensor
2023-06-02 feat: display a/c fan mode
2023-06-03 feat: show hostory of temperature
2023-06-03 feat: control a/c fan speed
2023-06-04 feat: track battery of thermometer
2023-06-07 feat: power off the screen when inactive
2023-06-07 fix: make power off time configurable
2023-06-07 fix: power on hdmi at startup
2023-06-09 docs: add hardware assembly instructions
2023-06-09 docs: scale wiring image
2023-06-09 docs: add case assembly instructions
2023-06-10 fix: smoothen deistance sensor data
    [distance.py]
2023-06-10 fix: make sure that distance process restarts when not responding
    [distance.py]
2023-06-13 feat: display current distance from the sensor
2023-06-14 fix: make distance sensor react faster
2023-06-14 fix: tweak distance script
    [distance.py]
2023-06-15 fix: improve network error handling
    [distance.py]
2023-06-15 feat: show distance sensor progress bar
2023-06-16 feat: measure CPU Temperature
2023-06-16 fix: group client logs
    [index.js]
2023-06-16 fix: add loading screen
    [index.js]
2023-06-17 refactor: decomponse demo socket
2023-06-17 docs: descibe cooling fan mount
    [wiring.fzz]
2023-06-17 feat: control CPU fan
2023-06-17 feat: add automatic cpu fan control
2023-06-17 fix: tweak cpu fan auto
2023-06-18 docs: add touch screen to wiring diagram
    [wiring.fzz]
2023-06-18 docs: document distance sensor and system monitor features
2023-06-20 feat: add reload button\
2023-06-20 fix: optimize covers screen
    [index.js]
2023-06-20 fix: optimize cpu fan anim
2023-06-21 fix: make sure that connecting message is removed once connected
    [index.js]
2023-06-22 fix: extend font load timeout
    [index.js]
2023-06-23 fix: connect to WS after loading all assets (more stable startup)
    [index.js]
2023-06-23 fix: rescale romm temperature chart
2023-06-23 fix: restart server when hitting reload button
    [index.js]
2024-09-15 fix room service
    [desk-hud-fan-mount.stl]
2024-09-15 add fan mount docs
2024-09-16 fix hdmi power ctrl in rpi5
